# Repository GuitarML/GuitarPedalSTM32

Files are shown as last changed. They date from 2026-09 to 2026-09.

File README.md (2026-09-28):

# STM32 Guitar Pedal

This is a custom STM32 digital guitar pedal with firmware programmed in c++ using STM32CubeIDE. It uses a STM32H7B0 Arm Cortex-M7 microcontroller 
running at 280MHz with 1.4MB SRAM and 128kb of flash. The PCB is designed using KiCad, and the JLCpcb Gerbers are included for easy ordering. This
pedal is capable of reverbs, delays, granular, filtering, amp and cabsims, and anything else you can think up.

[YouTube Walkthrough](https://www.youtube.com/watch?v=E03dCQ4MTPk)

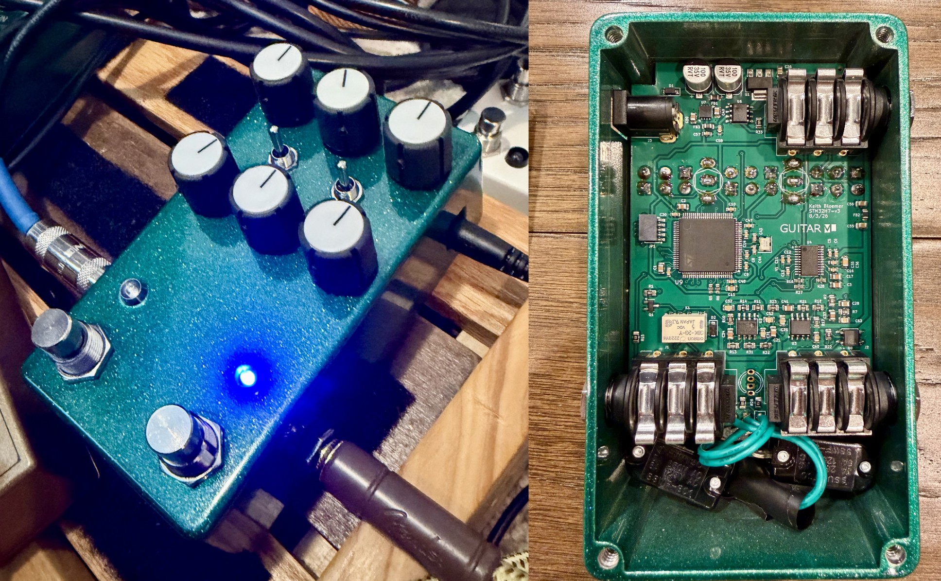
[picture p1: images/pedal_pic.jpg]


Hardware Features:
 - Mono input/output audio
 - Expression input
 - 6 knobs, 2 three-way SPDT switches (or subset of these if desired)
 - Two Footswitches
 - Optional single footswitch and 3 color RGB led (5mm) configuration
 - 9v DC center negative (standard guitar pedal power)
 - Buffered input/output when effect active
 - True Bypass Relay with active muting for quiet switching
 - 48kHz/24 bit digital audio processing (adjustable in code up to 216kHz with CS4270)
 - 4 layer pcb with internal ground planes

Dev Features:
 - 280MHz core processing speed
 - 1.4MB SRAM (1MB contiguous block available)
 - 128KB of Flash for storing programs
 - Cirrus Logic CS4270 codec (24-bit, 216 kHz, 105 dB dynamic range)
 - Code set up to use STM32CubeIde with c++
 - Program/Debug over 10 pin JTAG header using [ST-Link v3](https://www.digikey.com/en/products/detail/stmicroelectronics/STLINK-V3MINIE/16284301)

## Hardware

Typical build process:

1. Order the assembled PCB from JLCpcb (or other manufacturer), minimum 2 assembled. I use ENIG finish and keep the other pcb options as default. (Typical two week order time)
2. Order the soldered components (Six 16mm right angle potentiometers, 2 three way toggles, 2 Footswitches (and wire), Two 3mm LEDs, Two 3mm LED bezels) (Tayda, LoveMySwitches, Mouser, etc.) (Typical 1-2 week order time)
3. Order the drilled enclosure from Tayda (powder coat / UV print optional). (Varies two weeks to a month order time depending on how busy they are)
4. Solder potentiometers and switches (Ensure to insulate the toggle base using electrical tape, tight fit with potentiometers), and fit check with enclosure (use enclosure to ensure proper fit while soldering).
5. Remove pcb from enclosure, solder LEDs using enclosure as guide for height. (Double check pcb layout for correct orientation)
6. Solder wires to footswitches, solder footswitch wires to pcb.
7. Final install of pcb with all components, bolt on all components to enclosure. Install knobs on potentiometers.

IMPORTANT: When ordering the pcb using the included Gerbers, you will need to change the orientation of certain parts (most of the ICs) using the visualization tool (during JLCPcb's ordering process). This is because the part data from Kicad exported to the .pos file are different from what JLCpcb expects. Compare part orientation from their online tool to the Kicad PCB layout. Double check all ICs, relays, transistors, LDOs, and diodes.

IMPORTANT: The control layout spacing for the potentiometers and toggles is very tight. The toggle switch base must be insulated from the neighboring potentiometer legs or it could create a short. I typically wrap the base of the toggles in electrical tape twice to ensure proper insulation. 

IMPORTANT: The potentiometers require dust covers such as [these](https://www.taydaelectronics.com/dust-seal-covers-for-potentiometer.html) to avoid shorting out connections on the backside of the pcb.

NOTE: The power jack is intended to protrude from the pcb edge, fitting slightly into the rectangle cutout in the enclosure. May take some adjustment once potentiometers are soldered, recommended to adjust prior to soldering potentiometers/toggles, using the three 1/4" jack mounts to hold in place. 

Tayda Drill Templates:
[Two Footswitch, Two Single Color LED version](https://drill.taydakits.com/box-designs/new?public_key=b01XQ0p6RWl1NG9iTHYyMGtvVk8vdz09Cg==)
[Single Footswitch and RGB LED version](https://drill.taydakits.com/box-designs/new?public_key=N3oxTGpmM2x5Wk02WEdpMzExU3U5UT09Cg==)

NOTE: If you want to use the Single Footswitch/RGB LED version, you will need to change the peripheral settings. One of the footswitches changes from a GPIO input to a GPIO output (use pcb layout and schematic for guidance). Alternatively, you can change the LED pins from on/off GPIO outputs to Timer based PWM for brightness control. 

PCB from JLCpcb:
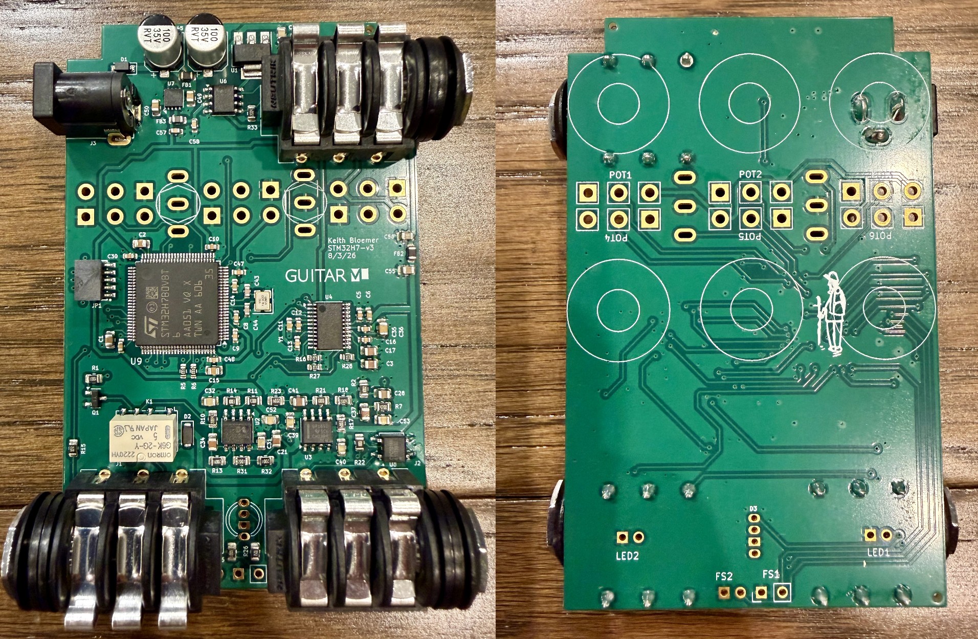
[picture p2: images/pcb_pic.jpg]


## Software

The effect in the main branch is an example delay/reverb using [DaisySP](https://github.com/electro-smith/daisysp). Other effects may be added as separate branches in this repo. I've found this to be the cleanest way to keep different configurations separate, rather than trying to comment out certain parts or use ifdef's. By default, the right footswitch is bypass, and the left footswitch is an aux function activated by holding the footswitch. This of course can be changed to whatever you want to do.

Connecting the pedal with ST-Link v3:
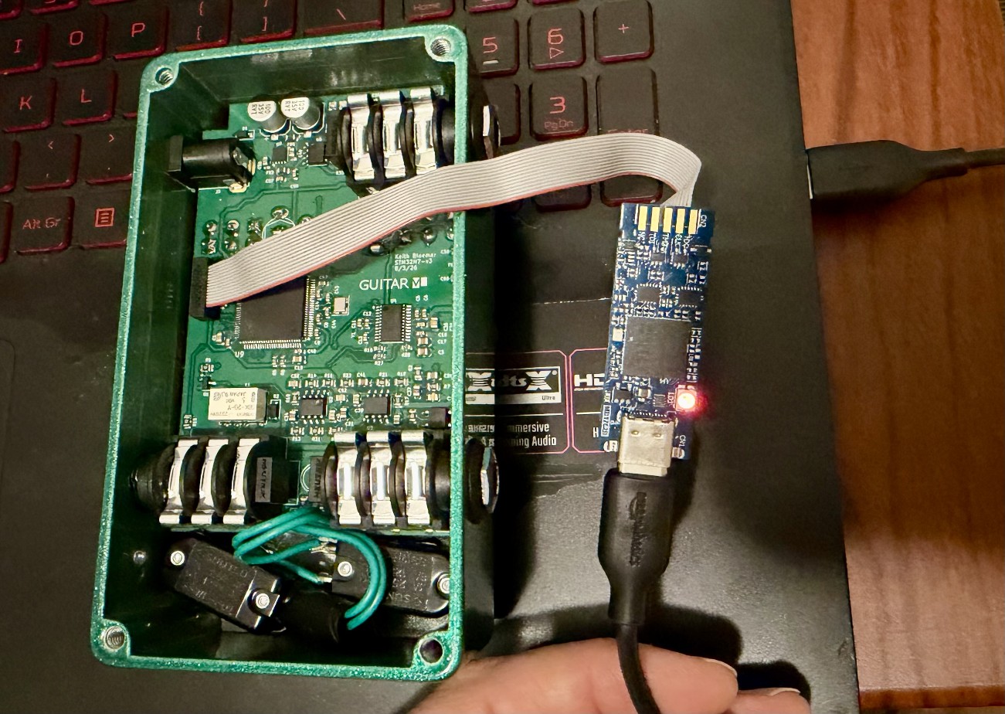
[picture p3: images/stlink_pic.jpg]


### Default Reverb/Delay

The example effect in the main branch is a Reverb/Delay using DaisySP.<br>
Controls:<br>
Knob1: Reverb Mix<br>
Knob2: Reverb Time<br>
Knob3: Reverb Filter (Damping)<br>
Knob4: Delay Mix<br>
Knob5: Delay Time<br>
Knob6: Delay Feedback<br>
<br>
Left Toggle is Routing<br>
Up: Delay into Reverb<br>
Center: Parallel Reverb/Delay<br>
Down: Reverb into Delay<br>
<br>
Right Toggle is Delay Mode<br>
Up: Normal Forward Delay<br>
Center: Octave Delay<br>
Down: Reverse Delay<br>
<br>
Right Footswitch is Bypass (pedal boots up in true bypass)<br>
Left Footswitch is Hold/Freeze (Holds reverb/delay feedback, no new signal to effects)<br>
<br>
Expression is an alternate control for Delay Time<br>

### Importing the Project

I use STM32CubeIDE version 2.2 for Windows. If you use a different version, migrating the code or updating your IDE may be required.

1. Clone the repository 
2. Open STM32CubeIDE.
3. Go to File > Import
4. Select General > Existing Projects into Workspace and click Next.
5. Browse to the Root Directory where you cloned the project. Ensure "Copy projects into workspace" is Unchecked. 
6. Click Finish.

### Set the Boot Configuration Bytes (option bytes)

You may need to use STM32CubeProgrammer to set the boot configuration bytes, telling the MCU to boot from flash.
If this is not set properly, it will work the first time after flashing from STM32CubeIDE, but after resetting power it will boot from the bootloader and not run your compiled program from flash memory.

Note: This can also be done in hardware, by pulling the boot pin low by connecting it to ground through a resistor. This wasn't required from my previous board using a different STM32H7, so I didn't do this on this hardware design. May be worth updating on future revisions.

1. Download and install STM32CubeProgrammer.
2. Connect the pedal via the 10 pin JTAG header using ST-Linkv3 and also apply power to the pedal from a 9v DC center negative adapter (the normal way you would power the pedal).
3. Select the JTAG port from the menu in STM32CubeProgrammer and Connect.
4. Navigate to "Boot address Option Bytes" and click drop down.
5. Modify both BOOT_CM7_ADD0 and BOOT_CM7_ADD1 rows to Value: "0x800" and Address: "0x08000000"  (no quotation marks)
6. Click Apply to save settings.
7. Verify the pedal boots from flash (runs your program) when cycling power.

### Using c++ instead of c with STM32CubeIDE

This project has been set up as a c++ project, however, STM32CubeIDE still auto generates a .c when moving from the MX view to the code view. As a work-around, if changes are made to the .ioc file in MX view, you will need to rename "main.cpp" to "main.c" beforehand. Once it is renamed, make the changes in MX and save and generate code. The code will be generated in "main.c". You can then rename "main.c" to "main.cpp" to compile the program. If you don't rename, a "main.c" file will be generated with your changes, and no changes will be made to "main.cpp".

## PCB Design Choices and Trade Offs

This particular pedal is intended as a platform for myself and others to design and test new guitar effect algorithms. As someone
coming from using the [Daisy Seed](https://daisy.audio/), I wanted to dive deeper into understanding how microcontrollers work,
and how to design custom boards using STM32. I also wanted to do something different from my Daisy Seed based [SoundSketch](https://github.com/GuitarML/SoundSketch),
rather than just try and recreate that same pedal without the Daisy Seed. The result is a more limited version of that pedal, using Mono processing,
expression, no Midi, and a slower MCU. It does have more internal SRAM (1.4MB vs 1MB), with a 1MB contiguous block (vs Daisy Seed / H750 512KB contiguous block), that 
can be used for things like data arrays and audio buffers.

There were also practical considerations / trade offs such as part availability and price through JLCpcb parts library. I wanted to design 
a high quality board while maintaining a minimal cost for pcb manufacturing and assembly. If you were to design your own board for commercial use you
may want to consider these trade-offs and make changes that best fit your needs:

1. CS4270 codec (discontinued but still in circulation and available at JLCPcb) chosen for cheap price (~$2.50) vs. later CS4272 or more modern TAC5242 (used on Daisy Seed v3).
2. Class 2 MLCC capacitors used in all locations except power filtering. For the audio path it's typically recommended to use Class 1 MLCC, Tantalum, or Electrolytic, due to Class 2 MLCCs being microphonic. Due to availability/price the Class 2 MLCCs are used in my design, but I haven't noticed lower quality audio or microphonic noise from the pedal.
3. Stereo audio jacks are used even though I only use Mono here. These are the ones typically available by JLCpcb, I haven't seen the mono, 1/4" board mounted jacks. The ring connection is unused and grounded.
4. Other improvements for manufacturing I've considered (but haven't gotten around to) is clip-in footswitches (ease of removing/installing if they go bad), and board mounted LEDs with light pipes (although this would require 2 sided assembly).

It was important to me that this design was a single board, with one sided assembly, to keep the price down, but a common practice in commercial pedals is to have a separate board for controls connected via a ribbon cable. This would allow for cheap repair if a potentiometer or switch goes bad.

When I ordered two assembled boards (with 3 blank pcbs due to minimum 5 at JLCpcb), the total price with shipping to USA was $250, with $90 of that being shipping/tariffs. The base price was around $160, which I think is reasonable. As the quantity goes up, the price per board decreases. This is due to the additional $3 per unique "Extended" part (as opposed to "Basic" parts) in the JLCpcb parts library. The $3 is a one time charge per unique Extended part in the BOM no matter how many pcbs you order. This fee is for manually loading the reels into the pick and place machine. The resistors/capacitors with standard values are "Basic", while pretty much everything else in this design is "Extended". 

## Acknowledgements

The pcb design and code rely heavily on what I learned from [Phil's Lab](https://www.youtube.com/@PhilsLab) YouTube channel, as well
as his related open source repositories on [Github](https://github.com/pms67). The final MCU/codec combination I use here is the same used
in the guitar pedal shown in many of the Phil's Lab videos. 

The reverbsc_in16 included here is a modified version of the [DaisySp](https://github.com/daisyaudio/DaisySP) reverbsc that uses int16 instead of floats in the audio buffer. This halves the amount of RAM used for the reverb.

The reverse delay effect by Adam Fulford, used in util/delayline_reverse.h.

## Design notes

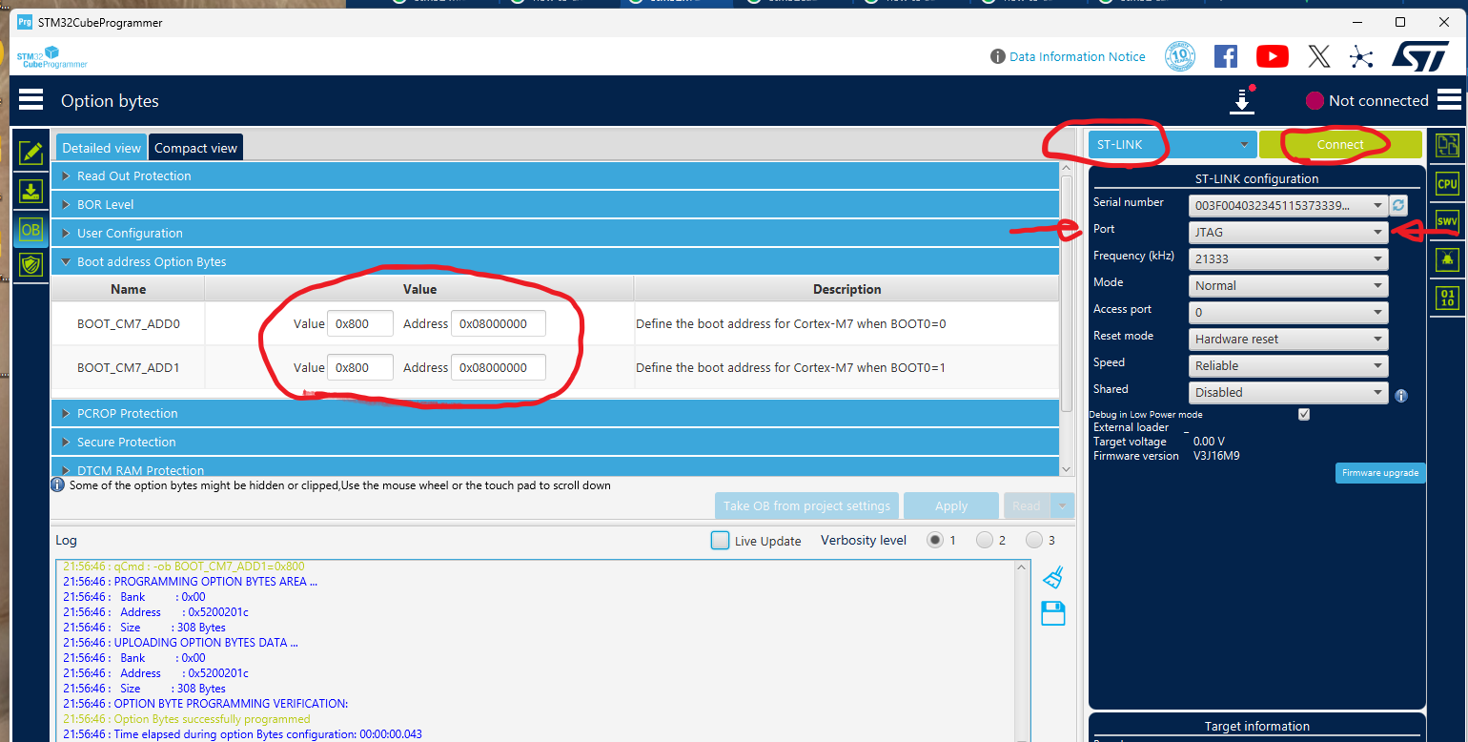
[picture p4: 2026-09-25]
images/set_BOOT_bytes_stm32CubeProgrammer_exampleH7B0.png

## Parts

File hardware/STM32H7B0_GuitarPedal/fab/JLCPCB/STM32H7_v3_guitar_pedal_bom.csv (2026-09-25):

Comment | Designator | Footprint | JLCPCB Part (optional)
2.2u | C1,C2,C15,C49,C50,C55,C56 | 805 | C377773
100n | C5,C7,C8,C9,C10,C12,C13,C14,C16,C30,C35,C47,C48,C57,C58 | 603 | C14663
1u | C6,C11 | 603 | C15849
10UF | C17,C21,C27,C34,C37,C41,C3 | 805 | C15850
100NF | C26,C31,C32,C39,C40 | 805 | C49678
3u3 | C28 | 805 | C16194987
47UF | C36 | 805 | C124129
10p | C43,C44 | 603 | C1634
100u 35V | C45,C46 | SMD,D6.3xL7.7mm | C3339
220p | C52 | 805 | C107145
2N7 | C53 | 805 | C170119
1N5817W | D1 | SOD-123 | C727113
1N4007W | D2 | SOD-123FL | C108803
600Ω@100MHz | FB1,FB2 | 805 | C1017
200Ω@100MHz | FB3 | 805 | C437407
NMJ6HCD2 | J1, J2, J5 |  | C368502
DC-005-20A | J3 |  | C136744
20021121-00010C4LF | JP1 | SMD,P=1.27mm | C150517
G6K-2G-Y DC5 | K1 | SMD,6.5x10mm | C397140
SS8050 | Q1 | SOT-23-3 | C2150
1K | R1,R22,R25 | 805 | C17513
10k | R2 | 805 | C17414
2.2k | R5,R6 | 603 | C4190
470R | R7 | 805 | C17710
2M | R10,R13,R17,R18,R23,R33 | 805 | C26112
100K | R11,R14 | 805 | C149504
1k5 | R15,R26 | 805 | C4310
5k1 | R16,R27,R28 | 603 | C23186
100R | R21 | 805 | C17408
2K | R31,R32 | 805 | C17604
LD1117S50CTR | U1 | SOT-223-3 | C81157
MCP6002T-I/SN | U2,U6 | SOIC-8 | C7377
OPA1652AIDR | U3 | SOIC-8 | C30025
CS4270 | U4 | TSSOP-24 | C1323229
Crystal_GND24 16Mhz | Y1 | SMD3225-4P | C112972
TLV76733QWDRBxQ1 | U7 | SON-8(3x3) | C5220143
CPC1018N | U8 | SOP-4-2.54mm | C133069
STM32H7B0VBT6 | U9 | LQFP-100(14x14) | C730227

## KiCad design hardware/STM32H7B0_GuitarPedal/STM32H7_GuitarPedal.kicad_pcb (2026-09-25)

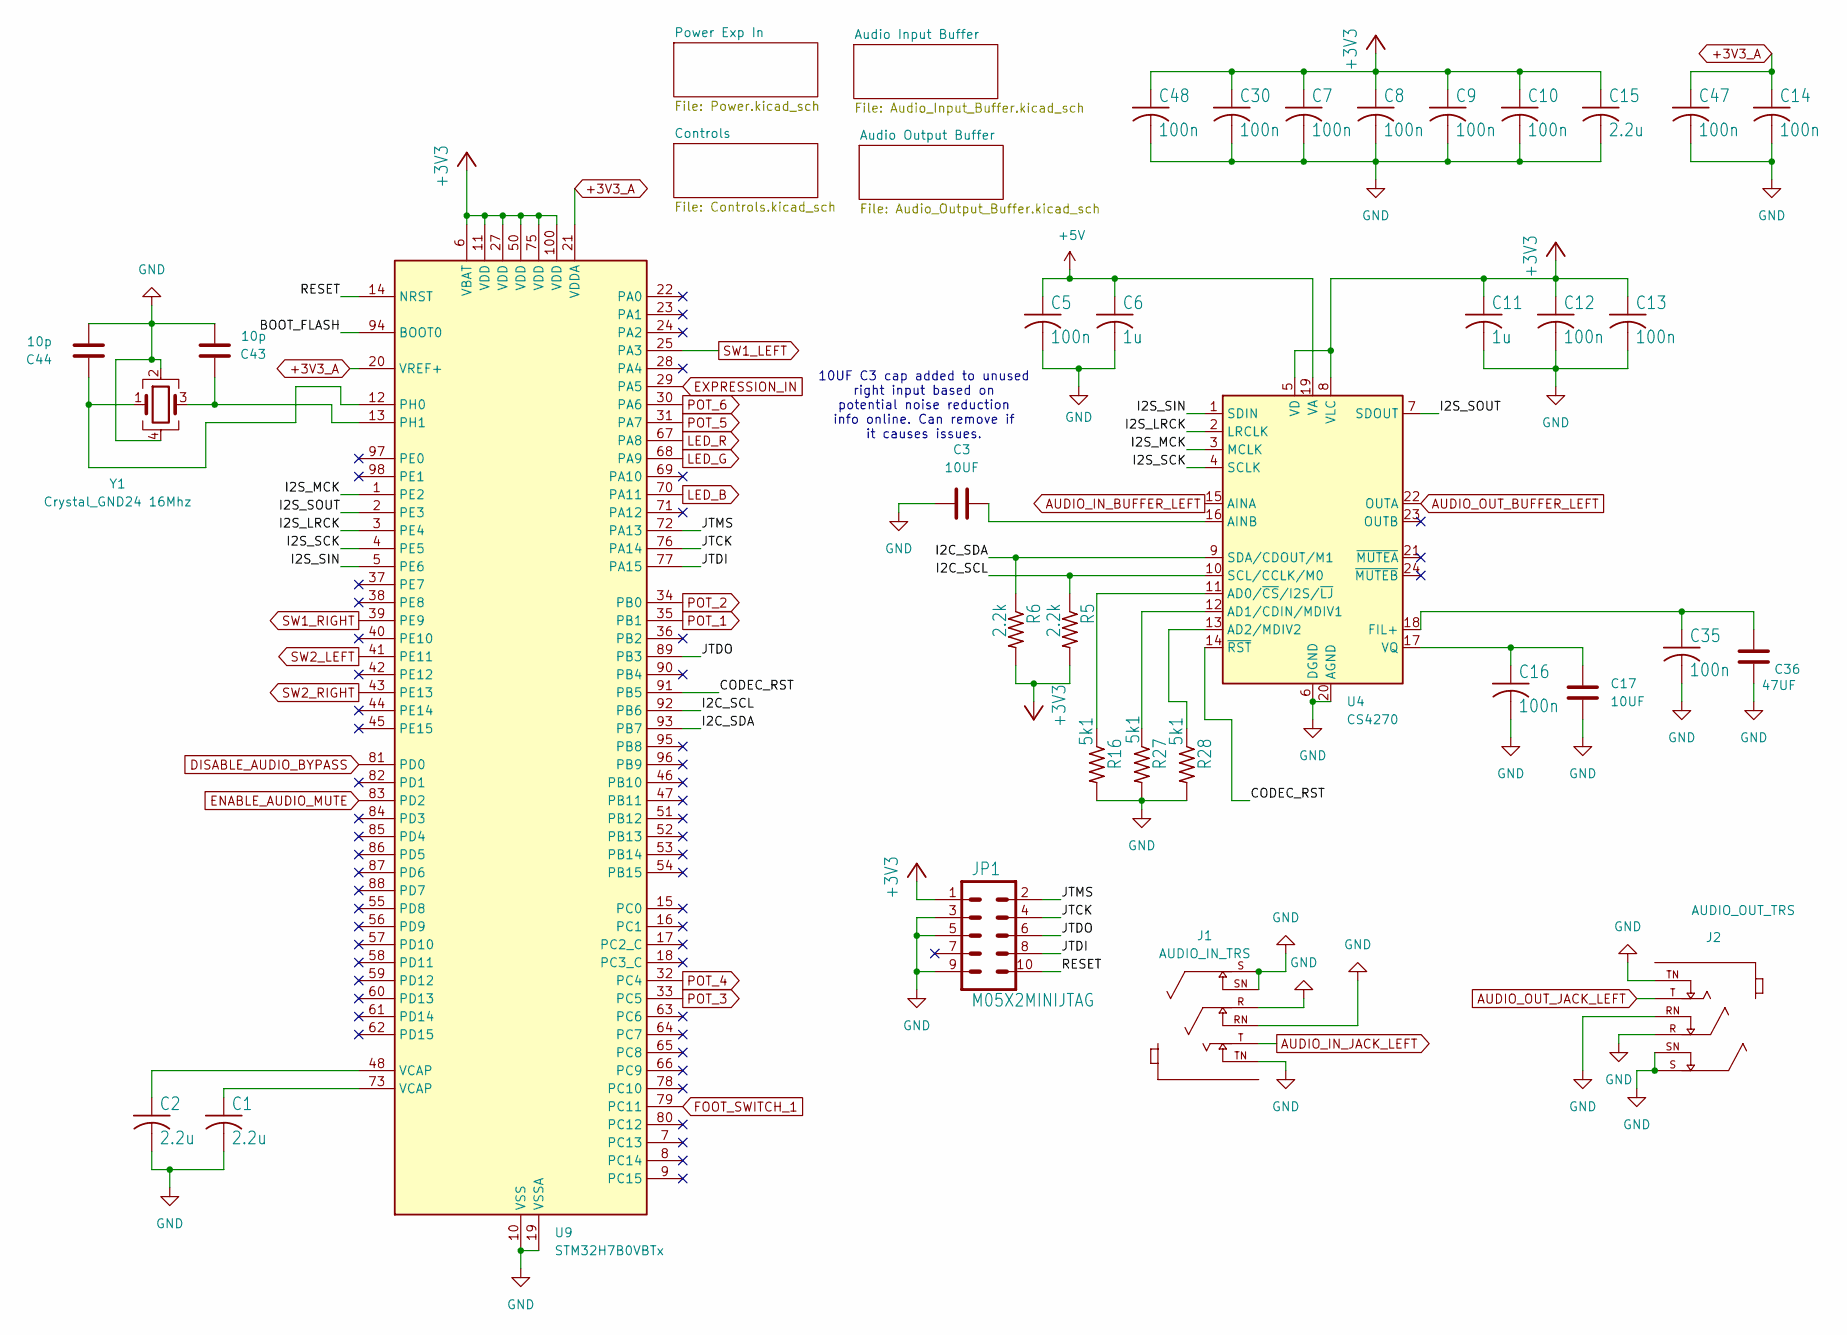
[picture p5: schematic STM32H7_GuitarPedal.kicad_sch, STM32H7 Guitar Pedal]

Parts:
C1, C2, C15: 2.2u; C_0805_2012Metric
C3, C17: 10UF; C_0805_2012Metric
C5, C7, C8, C9, C10, C12, C13, C14, C16, C30, C35, C47, C48: 100n; C_0603_1608Metric
C6, C11: 1u; C_0603_1608Metric
C36: 47UF; C_0805_2012Metric
C43, C44: 10p; C_0603_1608Metric
J1: AUDIO_IN_TRS; NEUTRIK_NMJ6HCD2; PARTREV 26.02.2021
J2: AUDIO_OUT_TRS; NEUTRIK_NMJ6HCD2; PARTREV 26.02.2021
JP1: M05X2MINIJTAG; 20021121-00010C4LF_JTAG
R5, R6: 2.2k; R_0603_1608Metric
R16, R27, R28: 5k1; R_0603_1608Metric
U4: CS4270; TSSOP-24_4.4x7.8mm_P0.65mm
U9: STM32H7B0VBTx; LQFP-100_14x14mm_P0.5mm
Y1: Crystal_GND24 16Mhz; Crystal_SMD_3225-4Pin_3.2x2.5mm

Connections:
+3V3: C7.1, C8.1, C9.1, C10.1, C11.1, C12.1, C13.1, C15.1, C30.1, C48.1, JP1.1, R5.2, R6.2, U4.5 (VD), U4.8 (VLC), U9.6 (VBAT), U9.11 (VDD), U9.27 (VDD), U9.50 (VDD), U9.75 (VDD), U9.100 (VDD); also elsewhere on the board
+3V3_A: C14.1, C47.1, U9.20 (VREF+), U9.21 (VDDA); also elsewhere on the board
+5V: C5.1, C6.1, U4.19 (VA); also elsewhere on the board
/BOOT_FLASH: U9.94 (BOOT0)
/CODEC_RST: U4.14 (~RST), U9.91 (PB5)
/I2C_SCL: R5.1, U4.10 (SCL/CCLK/M0), U9.92 (PB6)
/I2C_SDA: R6.1, U4.9 (SDA/CDOUT/M1), U9.93 (PB7)
/I2S_LRCK: U4.2 (LRCLK), U9.3 (PE4)
/I2S_MCK: U4.3 (MCLK), U9.1 (PE2)
/I2S_SCK: U4.4 (SCLK), U9.4 (PE5)
/I2S_SIN: U4.1 (SDIN), U9.5 (PE6)
/I2S_SOUT: U4.7 (SDOUT), U9.2 (PE3)
/JTCK: JP1.4, U9.76 (PA14)
/JTDI: JP1.8, U9.77 (PA15)
/JTDO: JP1.6, U9.89 (PB3)
/JTMS: JP1.2, U9.72 (PA13)
/RESET: JP1.10, U9.14 (NRST)
AUDIO_IN_BUFFER_LEFT: U4.15 (AINA); also elsewhere on the board
AUDIO_IN_JACK_LEFT: J1.T; also elsewhere on the board
AUDIO_OUT_BUFFER_LEFT: U4.22 (OUTA); also elsewhere on the board
AUDIO_OUT_JACK_LEFT: J2.T; also elsewhere on the board
DISABLE_AUDIO_BYPASS: U9.81 (PD0); also elsewhere on the board
ENABLE_AUDIO_MUTE: U9.83 (PD2); also elsewhere on the board
EXPRESSION_IN: U9.29 (PA5); also elsewhere on the board
FOOT_SWITCH_1: U9.79 (PC11); also elsewhere on the board
GND: C1.2, C2.2, C3.1, C5.2, C6.2, C7.2, C8.2, C9.2, C10.2, C11.2, C12.2, C13.2, C14.2, C15.2, C16.2, C17.2, C30.2, C35.2, C36.2, C43.1, C44.1, C47.2, C48.2, J1.R, J1.RN, J1.S, J1.SN, J1.TN, J2.R, J2.RN, J2.S, J2.SN, J2.TN, JP1.3, JP1.5, JP1.9, R16.2, R27.2, R28.2, U4.6 (DGND), U4.20 (AGND), U9.10 (VSS), U9.19 (VSSA), U9.26 (VSS), U9.49 (VSS), U9.74 (VSS), U9.99 (VSS), Y1.2, Y1.4; also elsewhere on the board
LED_B: U9.70 (PA11); also elsewhere on the board
LED_G: U9.68 (PA9); also elsewhere on the board
LED_R: U9.67 (PA8); also elsewhere on the board
unnamed: C1.1, U9.73 (VCAP)
unnamed: C2.1, U9.48 (VCAP)
unnamed: R16.1, U4.11 (AD0/~CS/I2S/~LJ)
unnamed: R27.1, U4.12 (AD1/CDIN/MDIV1)
unnamed: R28.1, U4.13 (AD2/MDIV2)
unnamed: C3.2, U4.16 (AINB)
unnamed: C35.1, C36.1, U4.18 (FIL+)
unnamed: C16.1, C17.1, U4.17 (VQ)
unnamed: C44.2, U9.12 (PH0), Y1.1
unnamed: C43.2, U9.13 (PH1), Y1.3
POT_1: U9.35 (PB1); also elsewhere on the board
POT_2: U9.34 (PB0); also elsewhere on the board
POT_3: U9.33 (PC5); also elsewhere on the board
POT_4: U9.32 (PC4); also elsewhere on the board
POT_5: U9.31 (PA7); also elsewhere on the board
POT_6: U9.30 (PA6); also elsewhere on the board
SW1_LEFT: U9.25 (PA3); also elsewhere on the board
SW1_RIGHT: U9.39 (PE9); also elsewhere on the board
SW2_LEFT: U9.41 (PE11); also elsewhere on the board
SW2_RIGHT: U9.43 (PE13); also elsewhere on the board

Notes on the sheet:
10UF C3 cap added to unused right input based on potential noise reduction info online. Can remove if it causes issues.

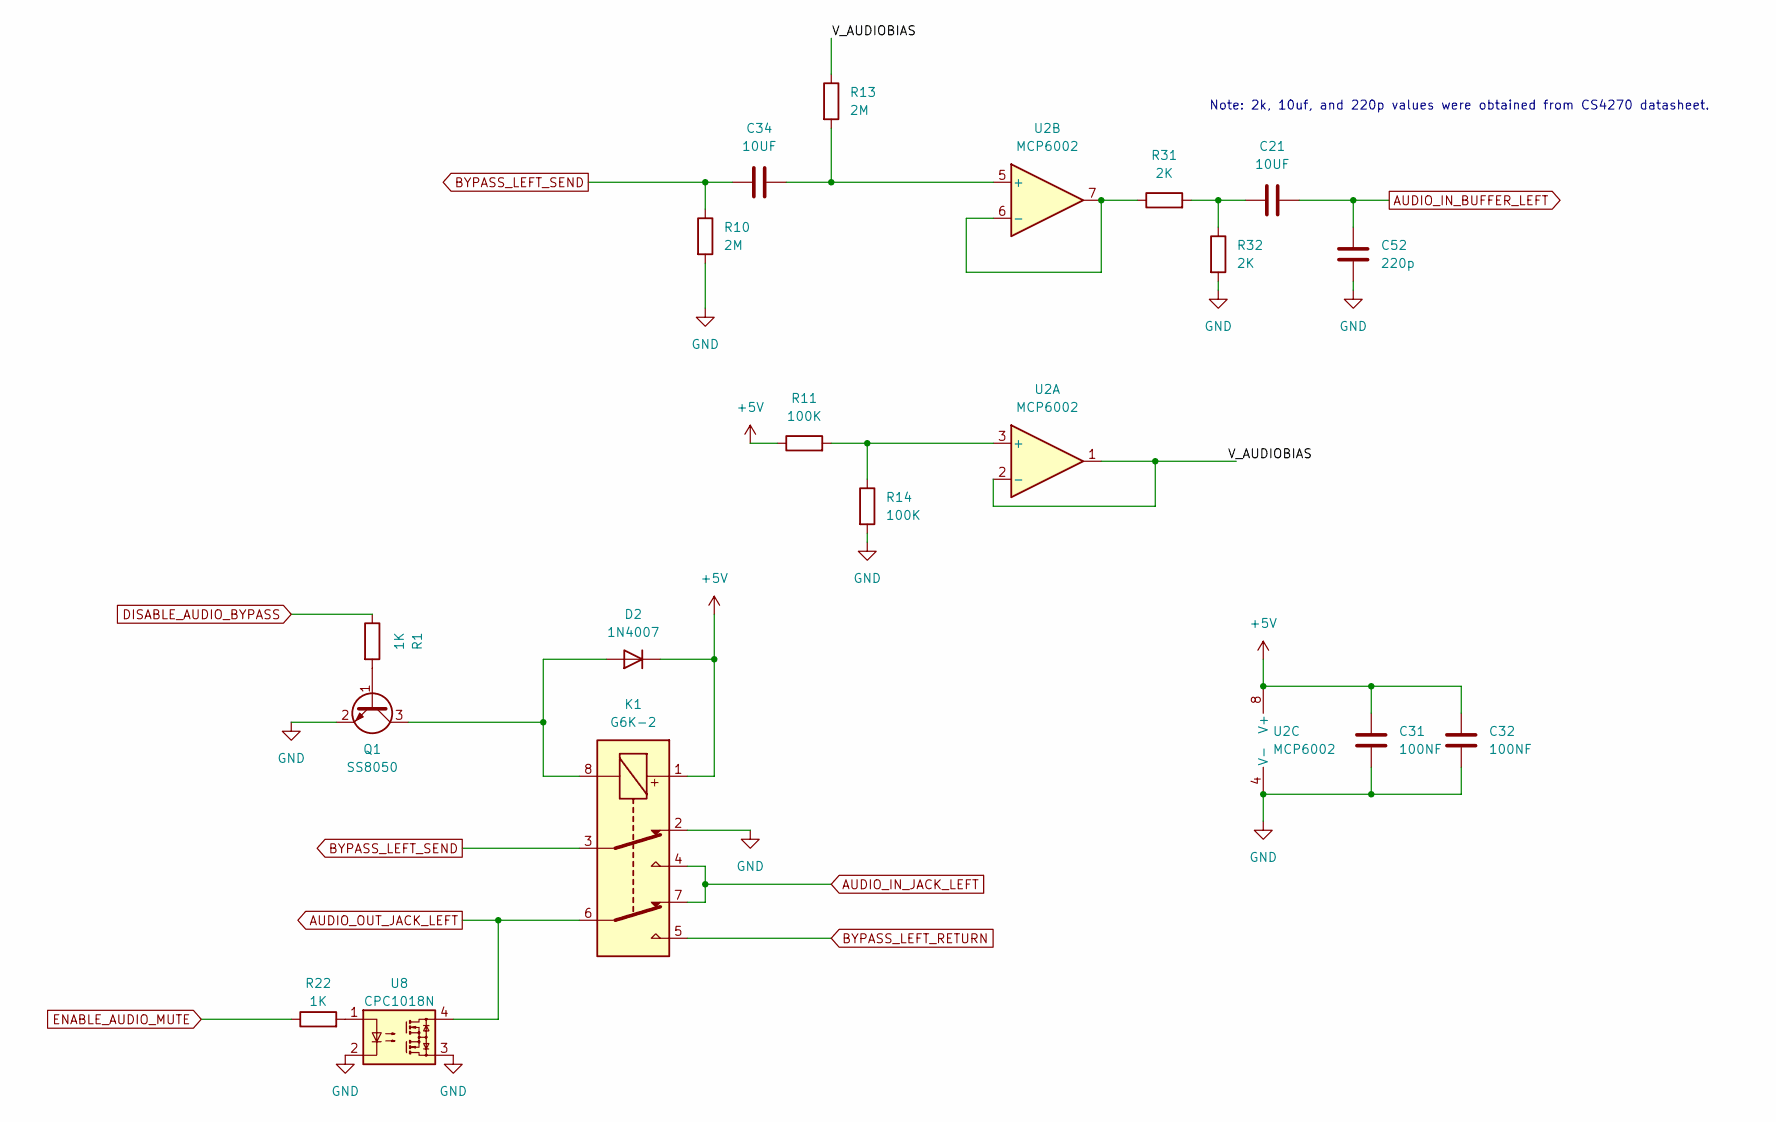
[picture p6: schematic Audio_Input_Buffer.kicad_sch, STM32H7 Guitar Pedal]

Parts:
C21, C34: 10UF; C_0805_2012Metric
C31, C32: 100NF; C_0805_2012Metric
C52: 220p; C_0805_2012Metric
D2: 1N4007; D_SOD-123F
K1: G6K-2; Relay_DPDT_Omron_G6K-2G-Y
Q1: SS8050; SOT-23-3
R1, R22: 1K; R_0805_2012Metric
R10, R13: 2M; R_0805_2012Metric
R11, R14: 100K; R_0805_2012Metric
R31, R32: 2K; R_0805_2012Metric
U2: MCP6002; SOIC-8_3.9x4.9mm_P1.27mm
U8: CPC1018N; SOP-4_3.8x4.1mm_P2.54mm

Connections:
+5V: C31.1, C32.1, D2.1 (K), K1.1, R11.1, U2.8 (V+); also elsewhere on the board
/Audio Input Buffer/V_AUDIOBIAS: R13.1, U2.1, U2.2 (-)
AUDIO_IN_BUFFER_LEFT: C21.2, C52.2; also elsewhere on the board
AUDIO_IN_JACK_LEFT: K1.4, K1.7; also elsewhere on the board
AUDIO_OUT_JACK_LEFT: K1.6, U8.4; also elsewhere on the board
BYPASS_LEFT_RETURN: K1.5; also elsewhere on the board
BYPASS_LEFT_SEND: C34.1, K1.3, R10.1
DISABLE_AUDIO_BYPASS: R1.1; also elsewhere on the board
ENABLE_AUDIO_MUTE: R22.1; also elsewhere on the board
GND: C31.2, C32.2, C52.1, K1.2, Q1.2 (E), R10.2, R14.2, R32.2, U2.4 (V-), U8.2, U8.3; also elsewhere on the board
unnamed: C21.1, R31.2, R32.1
unnamed: D2.2 (A), K1.8, Q1.3 (C)
unnamed: Q1.1 (B), R1.2
unnamed: R22.2, U8.1
unnamed: R11.2, R14.1, U2.3 (+)
unnamed: C34.2, R13.2, U2.5 (+)
unnamed: R31.1, U2.6 (-), U2.7

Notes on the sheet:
Note: 2k, 10uf, and 220p values were obtained from CS4270 datasheet.

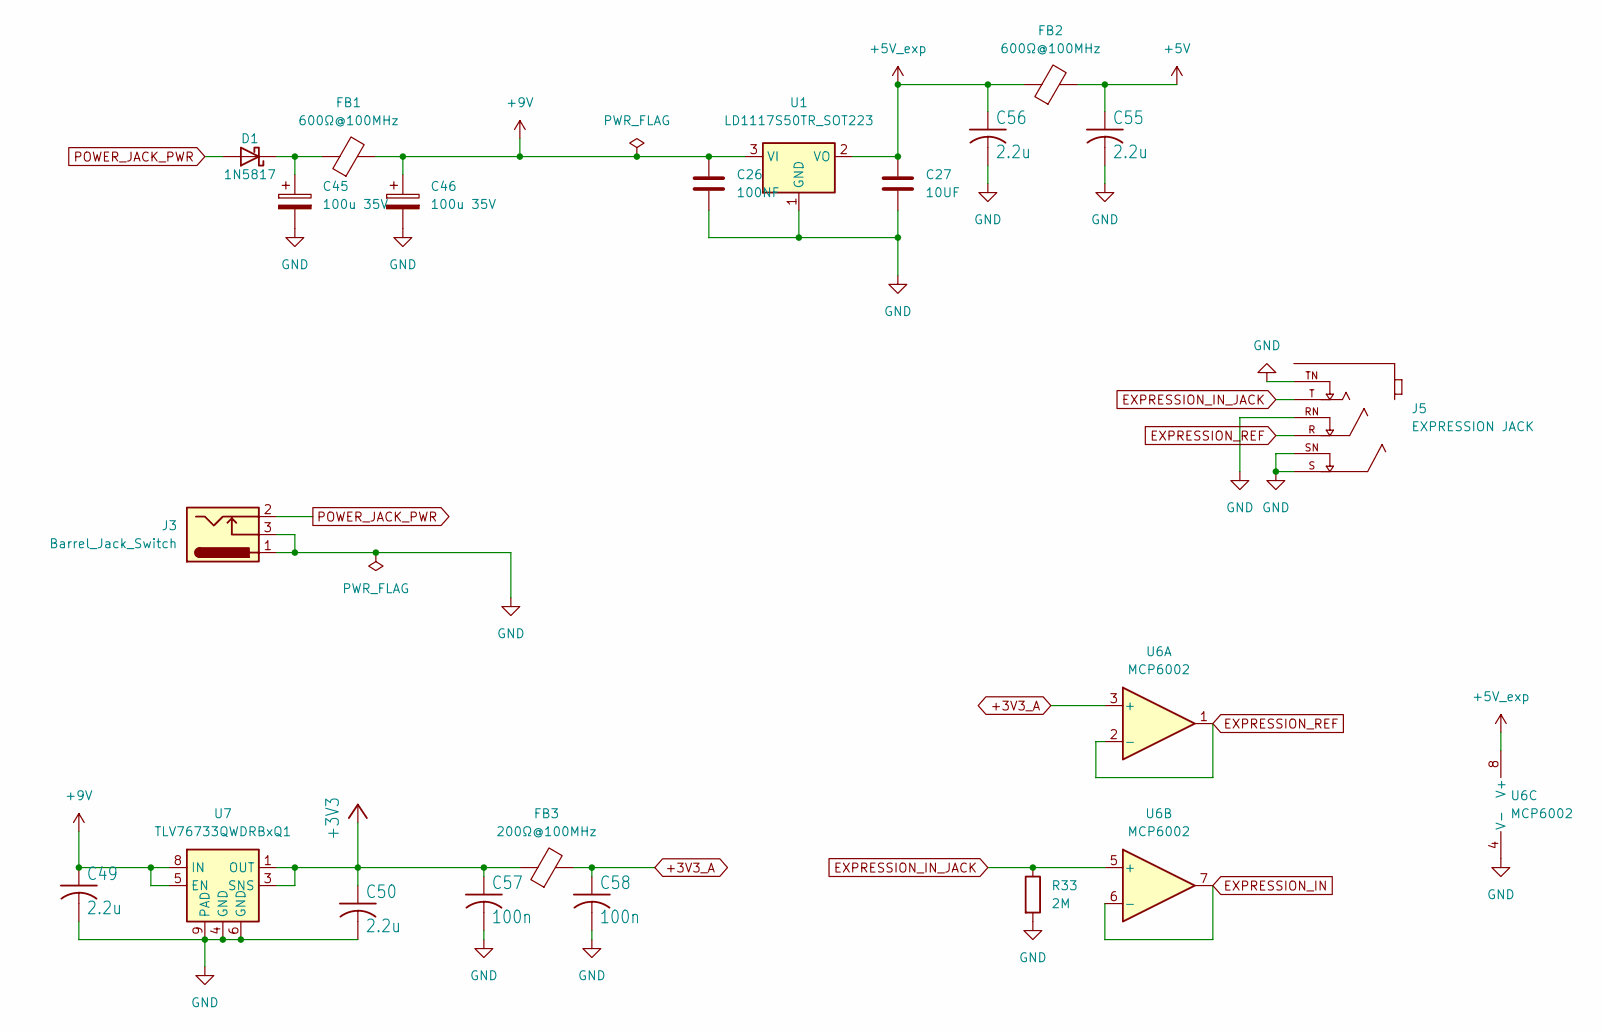
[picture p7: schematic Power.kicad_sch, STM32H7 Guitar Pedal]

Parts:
C26: 100NF; C_0805_2012Metric
C27: 10UF; C_0805_2012Metric
C45, C46: 100u 35V; CP_Elec_6.3x7.7; LCSC Part # C72478
C49, C50, C55, C56: 2.2u; C_0805_2012Metric
C57, C58: 100n; C_0603_1608Metric
D1: 1N5817; D_SOD-123
FB1, FB2: 600Ω@100MHz; L_0805_2012Metric; LCSC Part # C1017
FB3: 200Ω@100MHz; L_0805_2012Metric; LCSC Part # C1017
J3: Barrel_Jack_Switch; Generic_PowerJack
J5: EXPRESSION JACK; NEUTRIK_NMJ6HCD2; PARTREV 26.02.2021
R33: 2M; R_0805_2012Metric
U1: LD1117S50TR_SOT223; SOT-223-3_TabPin2
U6: MCP6002; SOIC-8_3.9x4.9mm_P1.27mm
U7: TLV76733QWDRBxQ1; VSON-8-1EP_3x3mm_P0.65mm_EP1.65x2.4mm

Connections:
+3V3: C50.1, C57.1, FB3.1, U7.1 (OUT), U7.3 (SNS); also elsewhere on the board
+3V3_A: C58.1, FB3.2, U6.3 (+); also elsewhere on the board
+5V: C55.1, FB2.2; also elsewhere on the board
+5V_exp: C27.1, C56.1, FB2.1, U1.2 (VO), U6.8 (V+)
+9V: C26.1, C46.1, C49.1, FB1.2, U1.3 (VI), U7.5 (EN), U7.8 (IN)
EXPRESSION_IN: U6.6 (-), U6.7; also elsewhere on the board
EXPRESSION_IN_JACK: J5.T, R33.1, U6.5 (+)
EXPRESSION_REF: J5.R, U6.1, U6.2 (-)
GND: C26.2, C27.2, C45.2, C46.2, C49.2, C50.2, C55.2, C56.2, C57.2, C58.2, J3.1, J3.3, J5.RN, J5.S, J5.SN, J5.TN, R33.2, U1.1 (GND), U6.4 (V-), U7.4 (GND), U7.6 (GND), U7.9 (PAD); also elsewhere on the board
unnamed: C45.1, D1.1 (K), FB1.1
POWER_JACK_PWR: D1.2 (A), J3.2

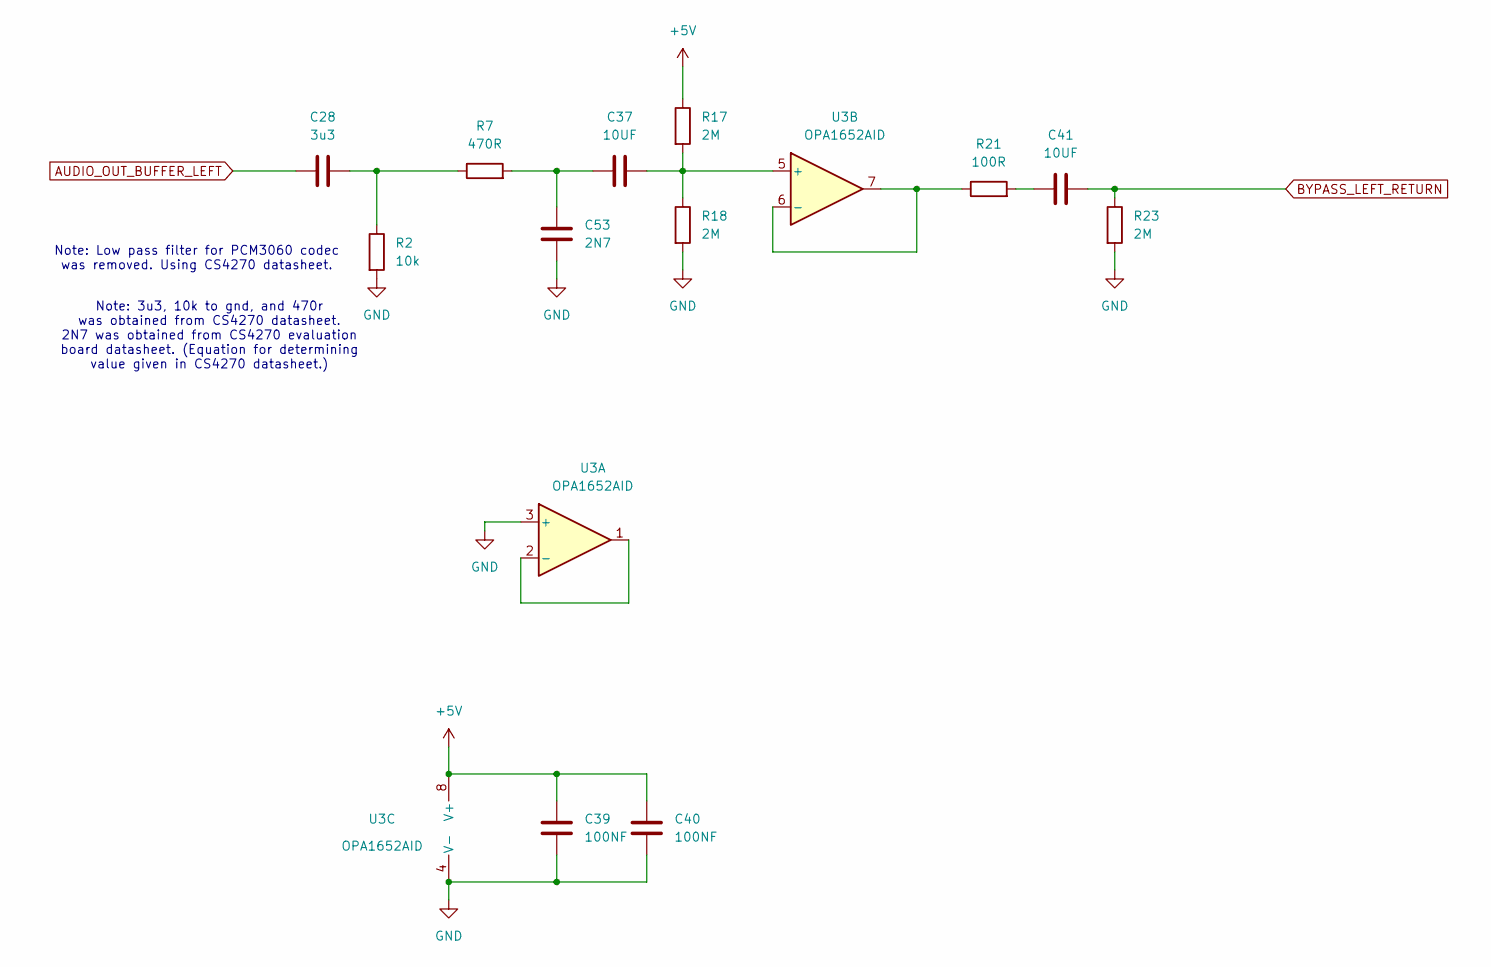
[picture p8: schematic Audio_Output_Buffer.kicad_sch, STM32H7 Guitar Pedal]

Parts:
C28: 3u3; C_0805_2012Metric
C37, C41: 10UF; C_0805_2012Metric
C39, C40: 100NF; C_0805_2012Metric
C53: 2N7; C_0805_2012Metric
R2: 10k; R_0805_2012Metric
R7: 470R; R_0805_2012Metric
R17, R18, R23: 2M; R_0805_2012Metric
R21: 100R; R_0805_2012Metric
U3: OPA1652AID; SOIC-8_3.9x4.9mm_P1.27mm

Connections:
+5V: C39.1, C40.1, R17.1, U3.8 (V+); also elsewhere on the board
AUDIO_OUT_BUFFER_LEFT: C28.1; also elsewhere on the board
BYPASS_LEFT_RETURN: C41.2, R23.1; also elsewhere on the board
GND: C39.2, C40.2, C53.2, R2.2, R18.2, R23.2, U3.3 (+), U3.4 (V-); also elsewhere on the board
unnamed: C28.2, R2.1, R7.1
unnamed: C37.2, C53.1, R7.2
unnamed: C41.1, R21.2
unnamed: U3.1, U3.2 (-)
unnamed: C37.1, R17.2, R18.1, U3.5 (+)
unnamed: R21.1, U3.6 (-), U3.7

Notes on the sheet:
Note: Low pass filter for PCM3060 codec was removed. Using CS4270 datasheet.
Note: 3u3, 10k to gnd, and 470r was obtained from CS4270 datasheet. 2N7 was obtained from CS4270 evaluation board datasheet. (Equation for determining value given in CS4270 datasheet.)

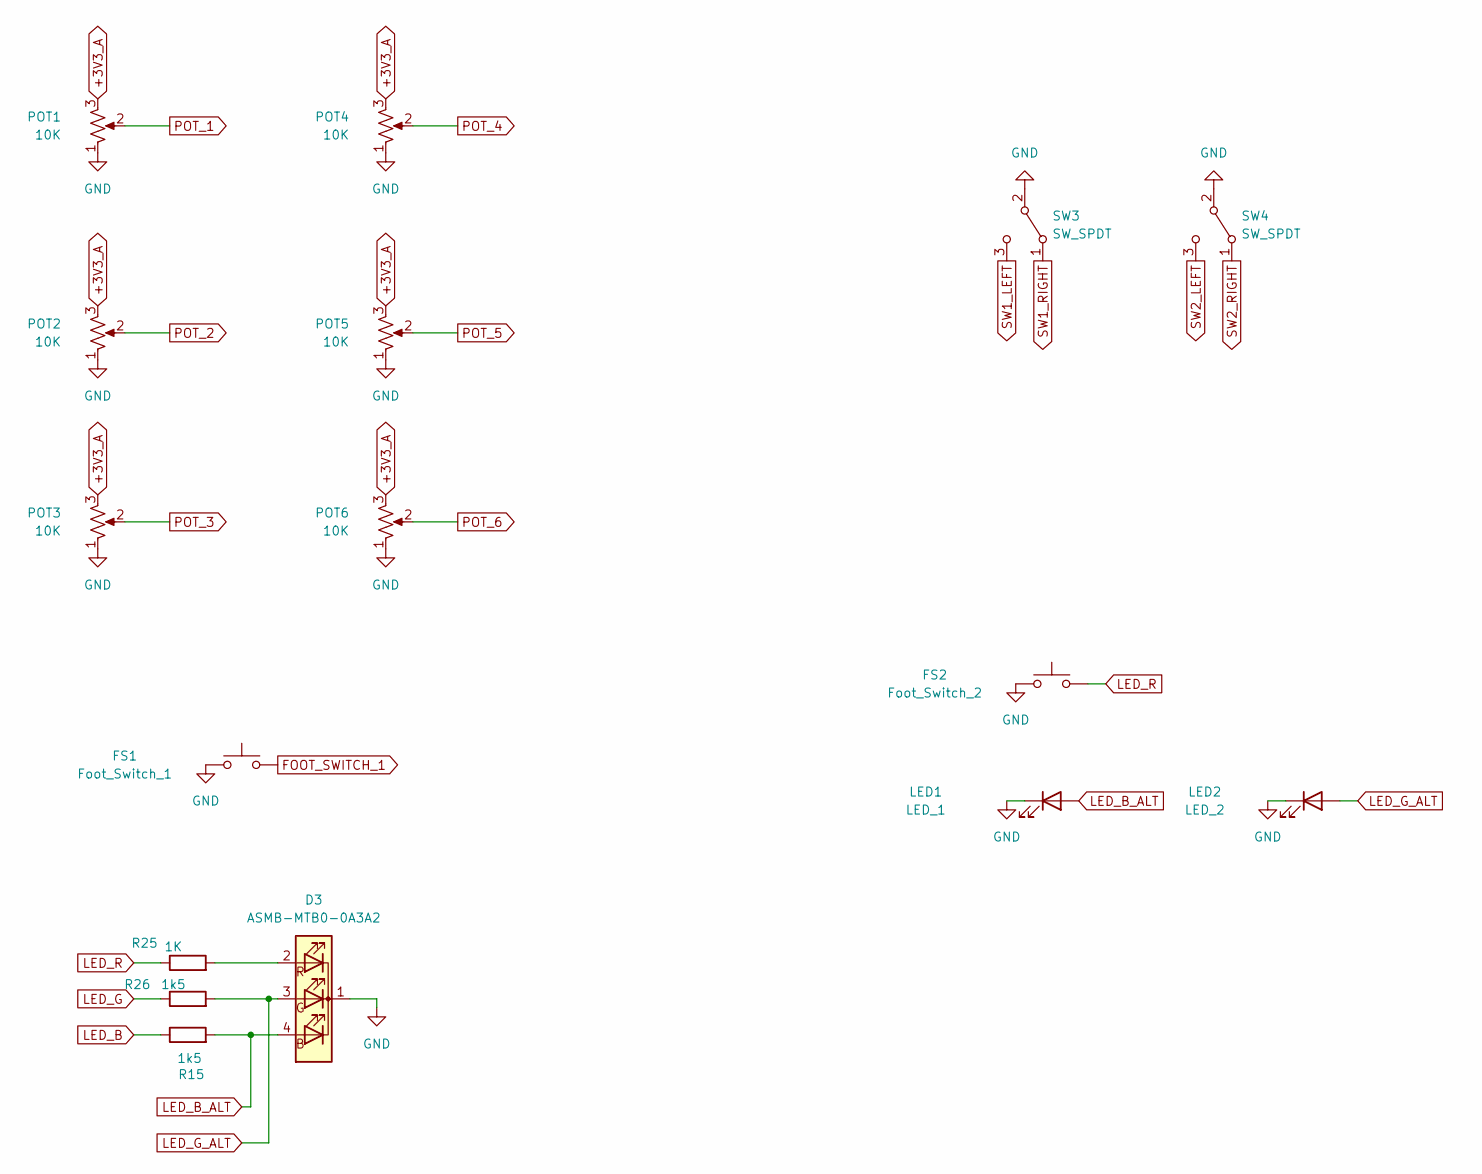
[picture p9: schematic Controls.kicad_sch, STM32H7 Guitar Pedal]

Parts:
D3: ASMB-MTB0-0A3A2; LED_D5.0mm-4_RGB
FS1: Foot_Switch_1; PinHeader_1x02_P2.54mm_Vertical
FS2: Foot_Switch_2; PinHeader_1x02_P2.54mm_Vertical
LED1: LED_1; PinHeader_1x02_P2.54mm_Vertical
LED2: LED_2; PinHeader_1x02_P2.54mm_Vertical
POT1, POT2, POT3, POT4, POT5, POT6: 10K; Pot_RightAngle_LongPin_16mm
R15, R26: 1k5; R_0805_2012Metric
R25: 1K; R_0805_2012Metric
SW3, SW4: SW_SPDT; SW_Toggle_SPDT_lugs

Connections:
+3V3_A: POT1.3, POT2.3, POT3.3, POT4.3, POT5.3, POT6.3; also elsewhere on the board
FOOT_SWITCH_1: FS1.2; also elsewhere on the board
GND: D3.1 (A), FS1.1, FS2.1, LED1.1 (K), LED2.1 (K), POT1.1, POT2.1, POT3.1, POT4.1, POT5.1, POT6.1, SW3.2 (B), SW4.2 (B); also elsewhere on the board
LED_B: R15.1; also elsewhere on the board
LED_B_ALT: D3.4 (BK), LED1.2 (A), R15.2
LED_G: R26.1; also elsewhere on the board
LED_G_ALT: D3.3 (GK), LED2.2 (A), R26.2
LED_R: FS2.2, R25.1; also elsewhere on the board
unnamed: D3.2 (RK), R25.2
POT_1: POT1.2; also elsewhere on the board
POT_2: POT2.2; also elsewhere on the board
POT_3: POT3.2; also elsewhere on the board
POT_4: POT4.2; also elsewhere on the board
POT_5: POT5.2; also elsewhere on the board
POT_6: POT6.2; also elsewhere on the board
SW1_LEFT: SW3.3 (C); also elsewhere on the board
SW1_RIGHT: SW3.1 (A); also elsewhere on the board
SW2_LEFT: SW4.3 (C); also elsewhere on the board
SW2_RIGHT: SW4.1 (A); also elsewhere on the board

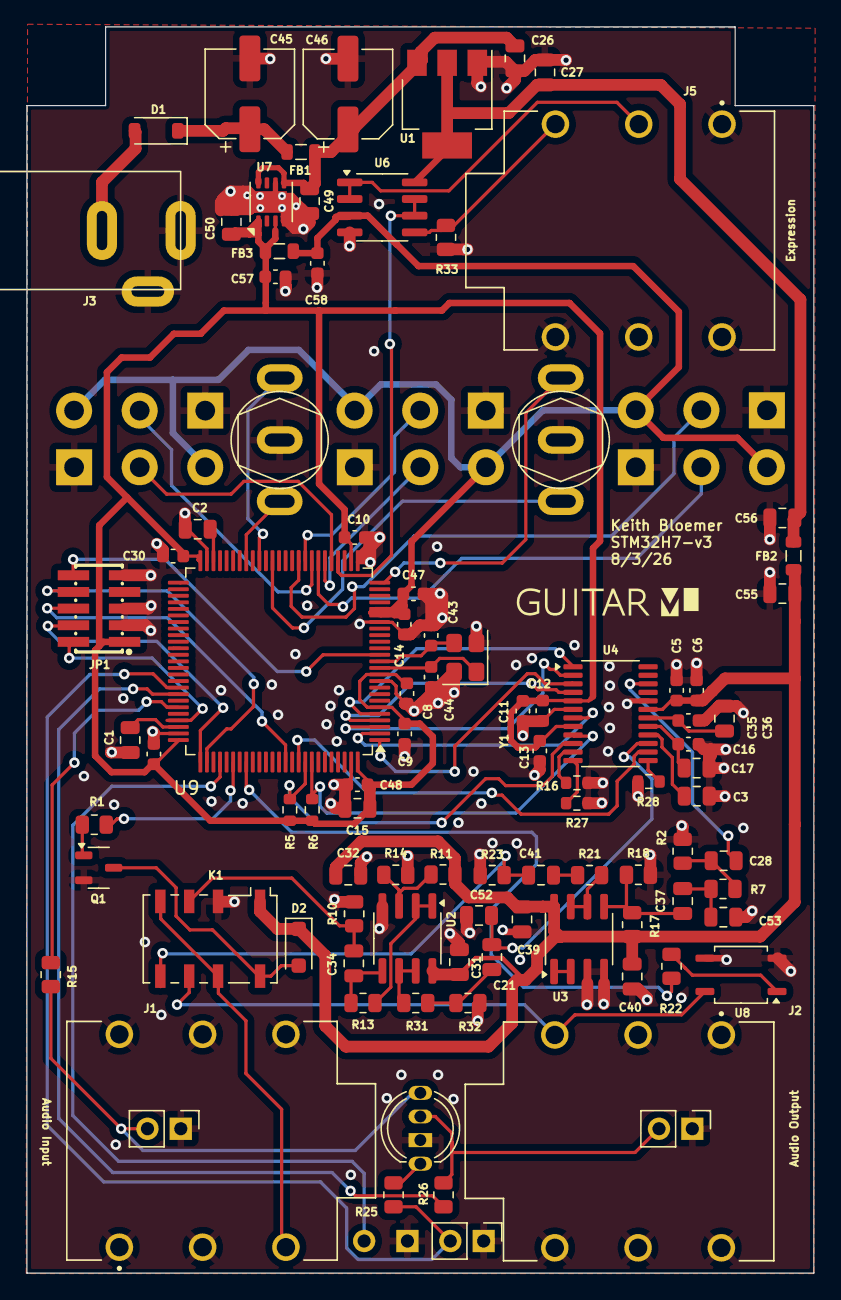
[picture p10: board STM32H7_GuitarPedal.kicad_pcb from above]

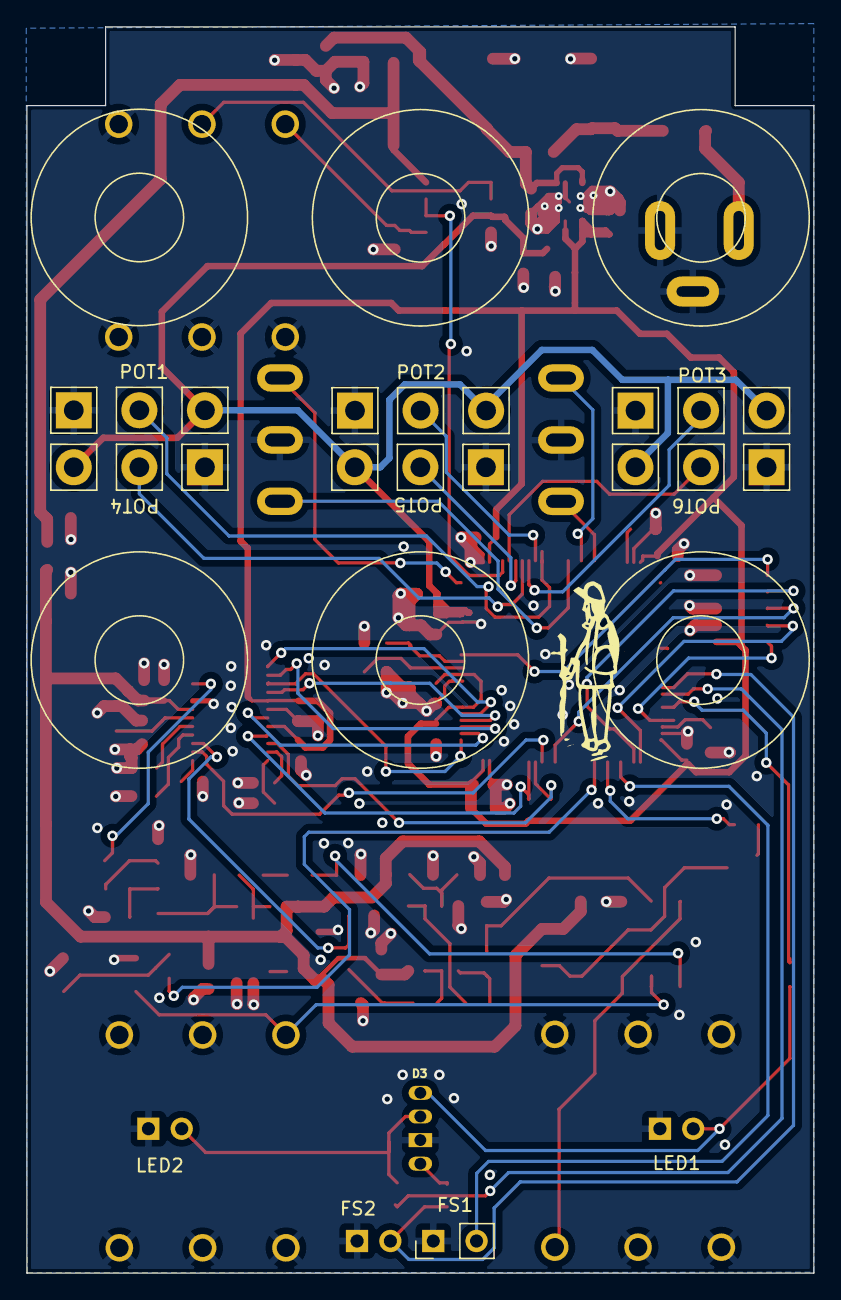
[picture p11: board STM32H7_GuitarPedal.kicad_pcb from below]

Board: 4 copper layers, 60.0 x 95.0 mm, 101 parts (7 on the bottom side), 73 nets.

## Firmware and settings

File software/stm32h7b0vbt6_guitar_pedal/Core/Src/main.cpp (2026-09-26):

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
/* Includes ------------------------------------------------------------------*/
#include "main.h"

/* USER CODE BEGIN Includes */
#include "CS4270-Codec.h"
#include "../../../deps/DaisySP/Source/daisysp.h"
#include "../../../util/reverbsc_int16.h"
#include "../../../util/Delays/delayline_reverse.h"
#include "../../../util/Delays/delayline_revoct.h"



/* USER CODE END Includes */

/* USER CODE BEGIN PD */

#define SAMPLING_FREQUENCY_HZ 48000.0f

#define UINT16_TO_FLOAT 0.00001525878f
#define INT16_TO_FLOAT 	0.00003051757f
#define FLOAT_TO_INT16 	32768.0f

#define AUDIO_BUFFER_SIZE 48

// Number of ADC channels for controls (potentiometers)
#define CONTROL_SETTING_COUNT 7

// Controls have to be changed by +- this percentage amount to update FX parameters
#define CONTROL_SETTING_CHANGE_THRESHOLD 0.005f

/* USER CODE END PD */

ADC_HandleTypeDef hadc1;
DMA_HandleTypeDef hdma_adc1;

I2C_HandleTypeDef hi2c1;

SAI_HandleTypeDef hsai_BlockA1;
SAI_HandleTypeDef hsai_BlockB1;
DMA_HandleTypeDef hdma_sai1_a;
DMA_HandleTypeDef hdma_sai1_b;

TIM_HandleTypeDef htim3;

/* USER CODE BEGIN PV */


/* NON-CACHEABLE MEMORY */
int32_t adcBuf[AUDIO_BUFFER_SIZE] 		__attribute__ ((section(".audiobuffer")));
int32_t dacBuf[AUDIO_BUFFER_SIZE] 		__attribute__ ((section(".audiobuffer")));

static volatile int32_t *inBufPtr 		__attribute__ ((section(".audiobuffer")));
static volatile int32_t *outBufPtr 		__attribute__ ((section(".audiobuffer")));

volatile uint8_t processHalfFlag		__attribute__ ((section(".audiobuffer")));

volatile uint8_t controlSettingsLocked	__attribute__ ((section(".audiobuffer")));
volatile uint8_t controlSettingsFlag	__attribute__ ((section(".audiobuffer")));

volatile uint16_t controlSettingBuf[CONTROL_SETTING_COUNT] 	__attribute__ ((section(".audiobuffer")));
volatile float controlSetting[CONTROL_SETTING_COUNT]		__attribute__ ((section(".audiobuffer")));
float controlSettingAtAlt[CONTROL_SETTING_COUNT];  // Used for knob movement detection for alternate interval modes
volatile float  prevControlSetting[CONTROL_SETTING_COUNT]	__attribute__ ((section(".audiobuffer"))); // TODO Moved to global, see if knob turning works better


volatile float delayMix						        __attribute__ ((section(".audiobuffer")));
volatile float reverbMix						        __attribute__ ((section(".audiobuffer")));
volatile float verbTime					       	__attribute__ ((section(".audiobuffer")));
volatile float verbFreq					        __attribute__ ((section(".audiobuffer")));

volatile float previousDelayTimeKnob					        __attribute__ ((section(".audiobuffer")));
volatile float previousDelayTimeExp					        __attribute__ ((section(".audiobuffer")));

// Expression
bool expressionControl = false;

//Bypass footswitch
uint32_t bypass_threshold = 100;
uint32_t bypass_wait_timer = 100;
bool bypass = true;
uint8_t bypass_reset = 0;

uint32_t quiet_bypass_threshold = 40;  // TODO Test minumum threshold this will work (in milliseconds)
uint32_t quiet_bypass_wait_timer = 40;
uint8_t quiet_bypass_reset = 0;

//Aux footswitch
uint32_t aux_threshold = 100;
uint32_t aux_wait_timer = 100;
bool aux = false;
uint8_t aux_reset = 0;
bool holdMode = false;

float preHoldReverbFeedback = 0.0;
float preHoldDelayFeedback = 0.0;

// Toggle switches
int leftTogglePosition = 0; // 0=up, 1=middle. 2=down
int rightTogglePosition = 0;

float volume = 1.0;
float counter = -0.0001;


//Reverb
using namespace daisysp;
ReverbSc16 verb;


float signedINT16_to_float(int16_t s)
{
    return s * INT16_TO_FLOAT;
}

int16_t float_to_signedINT16(float sample)
{
    // Clamp the float to range [-1.0, 1.0]
    float clamped = std::max(-1.0f, std::min(1.0f, sample));

    // Scale to 16-bit integer range
    return (int16_t)(clamped * FLOAT_TO_INT16);
}

// Delay
constexpr size_t MAX_DELAY_NORM = static_cast<size_t>(48000.0f * 1.f);
constexpr size_t MAX_DELAY_REV = static_cast<size_t>(48000.0f * 2.f); // 2 second max delay (needs to be double for reverse, since read/write pointers are going
                                                                             // opposite directions in the buffer)

DelayLineRevOct<int16_t, MAX_DELAY_NORM> delayLine;
DelayLineReverse<int16_t, MAX_DELAY_REV> delayLineRev;


// This is the core delay struct, which actually includes two delays,
// one for forwared/octave, and one for reverse. This is required
// because the reverse delayline needs to be double the size of the
// normal delayline to have the same range of the Time control. Both
// delays are processed, with the main delay feeding into the reverse
// delay to allow for Reverse Octave. A lowpass filter is included in
// the feedback loop, which can tame the harsh high frequencies of the
// octave delay, or create a "fading into the distance" effect for the
// forward and reverse delays. A "level" param is included for modulation
// of the output volume, for stereo panning.
struct delayRevOct {
    DelayLineRevOct<int16_t, MAX_DELAY_NORM> *del;
    DelayLineReverse<int16_t, MAX_DELAY_REV> *delreverse;
    float currentDelay;
    float delayTarget;
    float feedback = 0.0;
    float active = false;
    bool reverseMode = false;
    Svf toneOctLP;            // Low Pass Filter removed for now
    float level = 1.0;         // Level multiplier of output, added for stereo modulation (unused here)
    float level_reverse = 1.0; // Level multiplier of output, added for stereo modulation
    bool dual_delay = false;
    bool secondTapOn = false;
    bool octMode = false;

    float Process(float in) {
        // set delay times
        fonepole(currentDelay, delayTarget, .0002f);
        del->SetDelay(currentDelay);
        delreverse->SetDelay1(currentDelay * 2);

        float del_read = signedINT16_to_float(del->Read());

        float read_reverse = signedINT16_to_float(delreverse->ReadRev()); // REVERSE

        float read = 0.0;
        if (reverseMode) {
            //read = toneOctLP.Process(read_reverse);
            read = read_reverse;
        } else if (octMode) {
            toneOctLP.Process(del_read);
            read = toneOctLP.Low();
        } else {
            read = del_read;
        }

        float secondTap = 0.0;
        if (secondTapOn) {
            secondTap = signedINT16_to_float(del->ReadSecondTap());
        }
        // float read2 = delreverse->ReadFwd();
        if (active) {
            del->Write(float_to_signedINT16((feedback * read) + in));
            delreverse->Write(float_to_signedINT16((feedback * read) + in)); // Writing the read from fwd/oct delay line allows for combining oct and rev for reverse octave!
            // delreverse->Write((feedback * read2) + in);
        } else {
            del->Write(float_to_signedINT16(feedback * read)); // if not active, don't write any new sound to buffer
            delreverse->Write(float_to_signedINT16(feedback * read));
            // delreverse->Write((feedback * read2));
        }

        if (dual_delay) {
            return read_reverse * level_reverse * 0.5 + (read + secondTap) * level * 0.5; // Half the volume to keep total level consistent
        } else if (reverseMode) {
            return read_reverse * level_reverse;
        } else {
            return (read + secondTap) * level;
        }
    }
};

delayRevOct delay1;




/* USER CODE END PV */

void SystemClock_Config(void);
void PeriphCommonClock_Config(void);
static void MPU_Config(void);
static void MX_GPIO_Init(void);
static void MX_DMA_Init(void);
static void MX_SAI1_Init(void);
static void MX_I2C1_Init(void);
static void MX_ADC1_Init(void);
static void MX_TIM3_Init(void);
/* USER CODE BEGIN PFP */


void Process_HalfBuffer() {

    controlSettingsLocked = 1;


    // Input samples  ( TODO: Remove right channel, not used in this hardware)
    static float leftIn	= 0.0f;
    static float rightIn = 0.0f;

    // Output samples
    static float leftOut	= 0.0f;
    static float rightOut	= 0.0f;

    // Timers used for footswitch debouncing and hardware mute for quiet relay bypass
    if (bypass_wait_timer < bypass_threshold) {
        bypass_wait_timer += 1;
    }

    if (quiet_bypass_wait_timer < quiet_bypass_threshold) {
        quiet_bypass_wait_timer += 1;
    }

    if (aux_wait_timer < aux_threshold) {
        aux_wait_timer += 1;
    }



    // Loop through half of audio buffer (double buffering), convert int->float, apply processing, convert float->int, set output buffers
    for (uint16_t sampleIndex = 0; sampleIndex < (AUDIO_BUFFER_SIZE/2) - 1; sampleIndex += 2) {

        /*
        * Convert current input samples (24-bits) to floats (two I2S data lines, two channels per data line)
        */

        // Extract 24-bits via bit mask
        inBufPtr[sampleIndex]		&= 0xFFFFFF;
        inBufPtr[sampleIndex + 1]	&= 0xFFFFFF;

        // Check if number is negative (sign bit)
        if (inBufPtr[sampleIndex] & 0x800000) {
            inBufPtr[sampleIndex] |= ~0xFFFFFF;
        }

        if (inBufPtr[sampleIndex + 1] & 0x800000) {
            inBufPtr[sampleIndex + 1] |= ~0xFFFFFF;
        }

        // Normalise to float (-1.0, +1.0)
        leftIn  = (float) inBufPtr[sampleIndex]     / (float) (0x7FFFFF);
        rightIn = (float) inBufPtr[sampleIndex + 1] / (float) (0x7FFFFF);

        /////////////////////////////////////////////////////////////////////////
        // BEGIN DSP ////////////////////////////////////////////////////////////
        ///////////////////////////////////////////////////////////////////////// 

        if (!bypass) { // Note: Originally did not bypass effect when true bypassed, but it produced a pop on start up
			float dryLevelAdjust = 1.2; // Level adjustment for dry signal to match true bypass level

			float sendl, sendr, wetl, wetr;  // Reverb Inputs/Outputs
			float reverb_out = 0.0;
			float delay_out = 0.0;

			float effectIn = leftIn;
			if (holdMode) {
				effectIn = 0.0;
			}

			if (leftTogglePosition == 1) { // Parallel Delay/Reverb
				sendl = sendr = effectIn;
				verb.Process(sendl, sendr, &wetl, &wetr);
				reverb_out = (wetl + wetr) / 2;

				// Process Delay
				delay_out = delay1.Process(effectIn);

			} else if (leftTogglePosition == 0) { //  Delay into Reverb
				// Process Delay
				delay_out = delay1.Process(effectIn) * delayMix;

				sendl = sendr = delay_out + effectIn;
				verb.Process(sendl, sendr, &wetl, &wetr);
				reverb_out = (wetl + wetr) / 2;

			} else if (leftTogglePosition == 2) { //  Reverb into Delay
				sendl = sendr = effectIn;
				verb.Process(sendl, sendr, &wetl, &wetr);
				reverb_out = (wetl + wetr) / 2;

				// Process Delay
				delay_out = delay1.Process(reverb_out * reverbMix + effectIn); // TODO should leftIn be included here? see what sounds better
			}


			if (leftTogglePosition == 1) { // Parallel Delay/Reverb
				leftOut = leftIn * dryLevelAdjust + reverbMix * reverb_out + delayMix * delay_out;
			} else if (leftTogglePosition == 0) { //  Delay into Reverb
				leftOut = leftIn * dryLevelAdjust + reverbMix * reverb_out;
			} else if (leftTogglePosition == 2) { //  Reverb into Delay
				leftOut = leftIn * dryLevelAdjust + delayMix * delay_out;
			}
        }

        /////////////////////////////////////////////////////////////////////////
        // END DSP ////////////////////////////////////////////////////////////
        ///////////////////////////////////////////////////////////////////////// 

        /*
        * Convert floats to 32-bit output samples
        */

        // Ensure output samples are within [-1.0,+1.0] range
        if (leftOut < -1.0f) {
            leftOut = -1.0f;
        } else if (leftOut > 1.0f) {
            leftOut =  1.0f;
        }

        if (rightOut < -1.0f) {
            rightOut = -1.0f;
        } else if (rightOut > 1.0f) {
            rightOut =  1.0f;
        }

        // Scale to 24-bit signed integer and set output buffer
        outBufPtr[sampleIndex]	   = (int32_t) (leftOut  * 0x7FFFFF);
        outBufPtr[sampleIndex + 1] = (int32_t) (rightOut * 0x7FFFFF);


    }

    controlSettingsLocked = 0;

}


/* ADC Callbacks */
void HAL_SAI_RxHalfCpltCallback(SAI_HandleTypeDef *hsai) {

	inBufPtr  = &(adcBuf[0]);
	outBufPtr = &(dacBuf[0]);

	Process_HalfBuffer();

}

void HAL_SAI_RxCpltCallback(SAI_HandleTypeDef *hsai) {

	inBufPtr  = &(adcBuf[AUDIO_BUFFER_SIZE/2]);
	outBufPtr = &(dacBuf[AUDIO_BUFFER_SIZE/2]);

	Process_HalfBuffer();

}

void HAL_ADC_ConvCpltCallback(ADC_HandleTypeDef *hadc) {

	if (hadc->Instance == ADC1) {

		controlSettingsFlag = 1;

	}

}



/* USER CODE END PFP */

/**
  * @brief  The application entry point.
  * @retval int
  */
int main(void)
{

  /* MPU Configuration--------------------------------------------------------*/
  MPU_Config();

  /* Enable the CPU Cache */

  /* Enable I-Cache---------------------------------------------------------*/
  SCB_EnableICache();

  /* Enable D-Cache---------------------------------------------------------*/
  SCB_EnableDCache();

  /* MCU Configuration--------------------------------------------------------*/

  /* Reset of all peripherals, Initializes the Flash interface and the Systick. */
  HAL_Init();

  /* Configure the system clock */
  SystemClock_Config();

  /* Configure the peripherals common clocks */
  PeriphCommonClock_Config();

  /* Initialize all configured peripherals */
  MX_GPIO_Init();
  MX_DMA_Init();
  MX_SAI1_Init();
  MX_I2C1_Init();
  MX_ADC1_Init();
  MX_TIM3_Init();
  /* USER CODE BEGIN 2 */

  // Potentiometer controls
  controlSetting[0] = 0.5f;
  controlSetting[1] = 0.5f;
  controlSetting[2] = 0.5f;
  controlSetting[3] = 0.5f;
  controlSetting[4] = 0.5f;
  controlSetting[5] = 0.5f;
  controlSetting[6] = 0.5f;

  prevControlSetting[0] = 0.0f;
  prevControlSetting[1] = 0.0f;
  prevControlSetting[2] = 0.0f;
  prevControlSetting[3] = 0.0f;
  prevControlSetting[4] = 0.0f;
  prevControlSetting[5] = 0.0f;
  prevControlSetting[6] = 0.0f;



  // Effects
  delayLine.Init();
  delayLineRev.Init();
  delay1.del = &delayLine;
  delay1.delreverse = &delayLineRev;
  delay1.delayTarget = 24000; // in samples
  delay1.feedback = 0.0;
  delay1.active = true;
  delay1.toneOctLP.Init(SAMPLING_FREQUENCY_HZ);
  delay1.toneOctLP.SetFreq(1000.0);

  previousDelayTimeKnob = 0.1;
  previousDelayTimeExp = 0.0;

  verb.Init(SAMPLING_FREQUENCY_HZ);

  HAL_StatusTypeDef halStatus;

  /* Initialise Control ADCs */

  halStatus = HAL_ADCEx_Calibration_Start(&hadc1, ADC_CALIB_OFFSET, ADC_SINGLE_ENDED);

  /* Start control setting ADCs and sampling timer */
  halStatus = HAL_ADC_Start_DMA(&hadc1, (uint32_t *) controlSettingBuf, CONTROL_SETTING_COUNT);
  halStatus = HAL_TIM_Base_Start(&htim3); // TODO Make sure timer reference is correct


  /* Initialise SAIs (to start clocks, so that codec PLL locks) */
  halStatus = HAL_SAI_Init(&hsai_BlockA1);
  halStatus = HAL_SAI_Init(&hsai_BlockB1);

  // Set bypass as default when powering on
  HAL_GPIO_WritePin(GPIOD, GPIO_PIN_0, GPIO_PIN_RESET);

  /*
   * Initialise codec
   */
  uint8_t codecInitStatus = CS4270_Init();

  /*
   * Start SAI DAC transmission
   */
  halStatus = HAL_SAI_Transmit_DMA(&hsai_BlockA1, (uint8_t *) dacBuf, AUDIO_BUFFER_SIZE);

  /*
   * Start SAI ADC reception
   */
  halStatus = HAL_SAI_Receive_DMA(&hsai_BlockB1,  (uint8_t *) adcBuf, AUDIO_BUFFER_SIZE);

  // Placeholders for using PWM for LEDs, currently just using GPIO, need to recheck values if using TIM code below
  //HAL_TIM_PWM_Start(&htim1, TIM_CHANNEL_2);
  //HAL_TIM_PWM_Start(&htim1, TIM_CHANNEL_3);
  //HAL_TIM_PWM_Start(&htim1, TIM_CHANNEL_4);


  /* USER CODE END 2 */

  /* Infinite loop */
  /* USER CODE BEGIN WHILE */
  while (1)
  {
    /* USER CODE END WHILE */

    /* USER CODE BEGIN 3 */
        ////////////////////////////////////////////////////////////////////////////////////////////////
        // Begin Knob Controls and Expression //////////////////////////////////////////////////////////
        ////////////////////////////////////////////////////////////////////////////////////////////////

	if ( controlSettingsFlag && !controlSettingsLocked ) {

		for (uint8_t controlSettingNum = 0; controlSettingNum < CONTROL_SETTING_COUNT; controlSettingNum++) {

			// Convert raw ADC readings to float (0 ... 1), and low-pass filter  TODO Removed for now, test if it helps later
			controlSetting[controlSettingNum] = UINT16_TO_FLOAT * controlSettingBuf[controlSettingNum];

			// UPDATE detecting change in parameters, if knob turned to slowly, wont detect change. compare to last time the controls were changed, not the previous adc reading
			// If large enough control setting change set control parameters
			float time_temp= 0.0;
			if ( (controlSetting[controlSettingNum] > (1.0f + CONTROL_SETTING_CHANGE_THRESHOLD) * prevControlSetting[controlSettingNum]) || (controlSetting[controlSettingNum] < (1.0f - CONTROL_SETTING_CHANGE_THRESHOLD) * prevControlSetting[controlSettingNum]) ) {

				// Shift samples  TODO Moved this here, see if it works better
				prevControlSetting[controlSettingNum] = controlSetting[controlSettingNum];

				switch (controlSettingNum) {

					case 0: {
						reverbMix = controlSetting[0];

						break;
                    }

					case 1: {
                    	verbTime = controlSetting[1];
                        time_temp = (float) verbTime;
                    	verb.SetFeedback(time_temp);
                    	preHoldReverbFeedback = time_temp;
						break;
                    }

					case 2: {
                    	verbFreq = controlSetting[2];
                    	verb.SetLpFreq(verbFreq * verbFreq * 16000.0 + 500.0); // 500 to 16500 Hz low pass filter on reverb

						break;
                    }

					case 3: {
						delayMix = controlSetting[3];

						break;
                    }

					case 4: {

                        // If the Knob4 ADC reading has changed, and currently under expression control +/- 0.005 then give control to Knob2
                        if ((controlSetting[4] > previousDelayTimeKnob + 0.003 || controlSetting[4] < previousDelayTimeKnob - 0.003) && expressionControl == true) {
                            expressionControl = false;
                        }

                        if (!expressionControl) {
    						float delayTime = controlSetting[4];
    						previousDelayTimeKnob = delayTime;
    						delay1.delayTarget = delayTime * 48000;

                        }


						break;
					}

					case 5: {
						float delayFeedback = controlSetting[5];
						delay1.feedback = delayFeedback;


					    break;


					}

					case 6: {  // EXPRESSION INPUT
                        // If the expression ADC reading has changed +/- 0.005 and currently under Knob2 control, then give control to expression
                        if ((controlSetting[6] > previousDelayTimeExp + 0.003 || controlSetting[6] < previousDelayTimeExp - 0.003) && expressionControl == false) {
                            expressionControl = true;
                        }

                        if (expressionControl) {
    						float delayTime = controlSetting[6];
    						previousDelayTimeExp = delayTime;
    						delay1.delayTarget = delayTime * 48000;

                        }

						break;
                    }

				}

			}

		}

		controlSettingsFlag = 0;
	}

        ////////////////////////////////////////////////////////////////////////////////////////////////
        // End Knob Controls and Expression ////////////////////////////////////////////////////////////
        ////////////////////////////////////////////////////////////////////////////////////////////////


        //////////////////////////////////////////////////////////////////////////////////////////////////
        // Begin Footswitches ////////////////////////////////////////////////////////////////////////////
        //////////////////////////////////////////////////////////////////////////////////////////////////

	// TODO Limit the frequency of pin reads here, as is done when reading the analog pins

	// Bypass Footswitch Action //////////////////////////////////////////////////////////////////////
	uint32_t bypass_footswitch = HAL_GPIO_ReadPin(GPIOC, GPIO_PIN_11);
	//uint32_t aux_footswitch = HAL_GPIO_ReadPin(GPIOC, GPIO_PIN_7);

	// GPIO_PIN_SET means not pressed
	// GPIO_PIN_RESET means pressed

	// Check if footswitch is pressed, the debouce wait is done, and the footswitch was previously not pressed (not held)

	if (bypass_footswitch == GPIO_PIN_RESET && bypass_wait_timer == bypass_threshold && bypass_reset == 0) {
		bypass_wait_timer = 0; // Start bypass wait timer for debouce
		bypass_reset = 1;      // 1 means footswitch is still held

	}

	if (bypass_wait_timer == bypass_threshold && bypass_footswitch == GPIO_PIN_SET && bypass_reset == 1) { // If the footswitch is let go

    // Mute audio for quiet bypass and start timer for unmuting
    HAL_GPIO_WritePin(GPIOD, GPIO_PIN_2, GPIO_PIN_SET);
    quiet_bypass_reset = 1;
    quiet_bypass_wait_timer = 0;

    bypass_reset = 0;
	bypass_wait_timer = 0; // Start bypass wait timer for debouce
    bypass = (bypass == false) ? true : false;

    if (bypass) {
      HAL_GPIO_WritePin(GPIOD, GPIO_PIN_0, GPIO_PIN_RESET);  // Bypass audio (true bypass relay)
      HAL_GPIO_WritePin(GPIOA, GPIO_PIN_11, GPIO_PIN_RESET); // Turn off led
        	
    } else {
      HAL_GPIO_WritePin(GPIOD, GPIO_PIN_0, GPIO_PIN_SET);  // Route audio through effect
      HAL_GPIO_WritePin(GPIOA, GPIO_PIN_11, GPIO_PIN_SET); // Turn on led

    }

	}

    // If bypass muting was triggered and timer has finished, unmute audio and reset timer
    if (quiet_bypass_wait_timer == quiet_bypass_threshold && quiet_bypass_reset == 1) {
      HAL_GPIO_WritePin(GPIOD, GPIO_PIN_2, GPIO_PIN_RESET);
      quiet_bypass_reset = 0;
    }



	// Aux Footswitch Action (Hold to engage, let go to disengage) //////////////////////////////////////
	    uint32_t aux_footswitch = HAL_GPIO_ReadPin(GPIOA, GPIO_PIN_8);
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

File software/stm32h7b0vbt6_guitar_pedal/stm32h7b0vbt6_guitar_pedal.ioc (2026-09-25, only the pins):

Mcu.UserName=STM32H7B0VBTx
PA11.Signal=GPIO_Output
PA13.Signal=DEBUG_JTMS-SWDIO
PA14.Signal=DEBUG_JTCK-SWCLK
PA15.Signal=DEBUG_JTDI
PA3.GPIO_Label=GPIO_INP_SW1_DOWN
PA3.Signal=GPIO_Input
PA5.GPIO_Label=ADC1_INP19_Expression
PA5.Signal=ADCx_INP19
PA6.GPIO_Label=ADC1_INP3_POT6
PA6.Signal=ADCx_INP3
PA7.GPIO_Label=ADC1_INP7_POT5
PA7.Signal=ADCx_INP7
PA8.GPIO_Label=GPIO_input_Footswitch2_or_ledR
PA8.Signal=GPIO_Input
PA9.Signal=GPIO_Output
PB0.GPIO_Label=ADC1_INP9_POT2
PB0.Signal=ADCx_INP9
PB1.GPIO_Label=ADC1_INP5_POT1
PB1.Signal=ADCx_INP5
PB3.Signal=DEBUG_JTDO-SWO
PB5.GPIO_Label=GPIO_Output_CODEC_RESET
PB5.Signal=GPIO_Output
PB6.Signal=I2C1_SCL
PB7.Signal=I2C1_SDA
PC11.GPIO_Label=GPIO_In_Footsw
PC11.Signal=GPIO_Input
PC4.GPIO_Label=ADC1_INP4_POT4
PC4.Signal=ADCx_INP4
PC5.GPIO_Label=ADC1_INP8_POT3
PC5.Signal=ADCx_INP8
PD0.GPIO_Label=GPIO_Out_Bypass
PD0.Signal=GPIO_Output
PD2.GPIO_Label=GPIO_Out_Mute
PD2.Signal=GPIO_Output
PE11.GPIO_Label=GPIO_INP_SW2_DOWN
PE11.Signal=GPIO_Input
PE13.GPIO_Label=GPIO_INP_SW2_UP
PE13.Signal=GPIO_Input
PE2.Signal=SAI1_MCLK_A
PE3.Signal=SAI1_SD_B
PE4.Signal=SAI1_FS_A
PE5.Signal=SAI1_SCK_A
PE6.Signal=SAI1_SD_A
PE9.GPIO_Label=GPIO_INP_SW1_UP
PE9.Signal=GPIO_Input
PH0-OSC_IN.Signal=RCC_OSC_IN
PH1-OSC_OUT.Signal=RCC_OSC_OUT

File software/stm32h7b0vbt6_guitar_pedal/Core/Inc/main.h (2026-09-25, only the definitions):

#define GPIO_INP_SW1_DOWN_Pin GPIO_PIN_3
#define GPIO_INP_SW1_DOWN_GPIO_Port GPIOA
#define ADC1_INP19_Expression_Pin GPIO_PIN_5
#define ADC1_INP19_Expression_GPIO_Port GPIOA
#define ADC1_INP3_POT6_Pin GPIO_PIN_6
#define ADC1_INP3_POT6_GPIO_Port GPIOA
#define ADC1_INP7_POT5_Pin GPIO_PIN_7
#define ADC1_INP7_POT5_GPIO_Port GPIOA
#define ADC1_INP4_POT4_Pin GPIO_PIN_4
#define ADC1_INP4_POT4_GPIO_Port GPIOC
#define ADC1_INP8_POT3_Pin GPIO_PIN_5
#define ADC1_INP8_POT3_GPIO_Port GPIOC
#define ADC1_INP9_POT2_Pin GPIO_PIN_0
#define ADC1_INP9_POT2_GPIO_Port GPIOB
#define ADC1_INP5_POT1_Pin GPIO_PIN_1
#define ADC1_INP5_POT1_GPIO_Port GPIOB
#define GPIO_INP_SW1_UP_Pin GPIO_PIN_9
#define GPIO_INP_SW1_UP_GPIO_Port GPIOE
#define GPIO_INP_SW2_DOWN_Pin GPIO_PIN_11
#define GPIO_INP_SW2_DOWN_GPIO_Port GPIOE
#define GPIO_INP_SW2_UP_Pin GPIO_PIN_13
#define GPIO_INP_SW2_UP_GPIO_Port GPIOE
#define GPIO_input_Footswitch2_or_ledR_Pin GPIO_PIN_8
#define GPIO_input_Footswitch2_or_ledR_GPIO_Port GPIOA
#define GPIO_In_Footsw_Pin GPIO_PIN_11
#define GPIO_In_Footsw_GPIO_Port GPIOC
#define GPIO_Out_Bypass_Pin GPIO_PIN_0
#define GPIO_Out_Bypass_GPIO_Port GPIOD
#define GPIO_Out_Mute_Pin GPIO_PIN_2
#define GPIO_Out_Mute_GPIO_Port GPIOD
#define GPIO_Output_CODEC_RESET_Pin GPIO_PIN_5
#define GPIO_Output_CODEC_RESET_GPIO_Port GPIOB

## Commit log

2026-09-26 Updated drill template links
2026-09-26 Added octave and reverse delay modes on toggle 2
    [main.cpp]
2026-09-26 Added low pass filter on octave, updated bypass logic

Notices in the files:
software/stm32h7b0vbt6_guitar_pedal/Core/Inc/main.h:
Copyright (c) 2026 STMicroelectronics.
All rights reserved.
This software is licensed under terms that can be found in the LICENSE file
